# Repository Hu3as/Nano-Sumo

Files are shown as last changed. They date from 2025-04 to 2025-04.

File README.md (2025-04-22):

## <div align="center">Nano sumo fighting robots</div>

 <div align="center">
A robot designed and built as an interactive showcase for a student research group. The set includes two robots in different colors, programmed to detect their opponent using sensors and push them out of the play area. The arena is defined by a special mat or a highly visible tape.
The project is built using three custom-designed PCBs that I developed. These boards integrate a battery management system, an STM32 microcontroller, an LED with a control button, a motor driver, two micro motors, and four optical sensors that detect both the opponent’s position and the boundary lines of the play area.
 </div>

<div align="center">

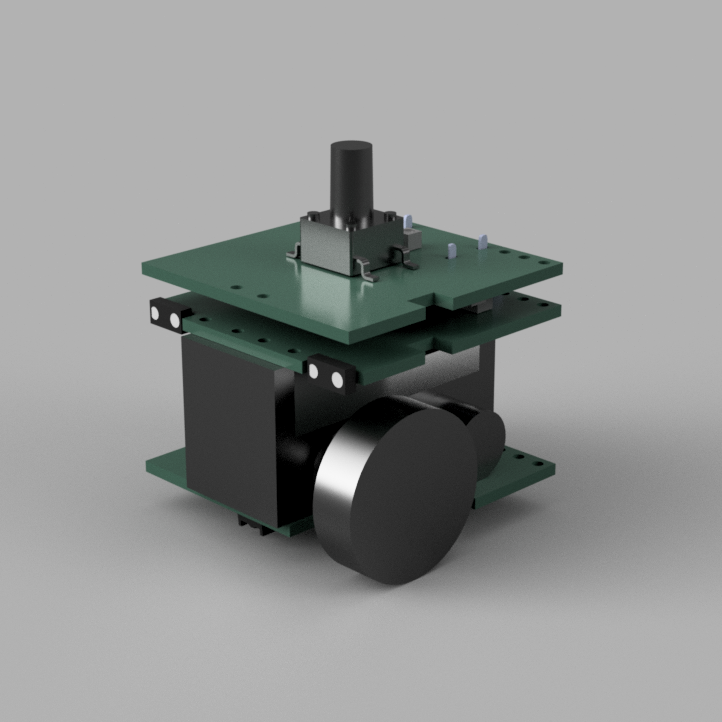
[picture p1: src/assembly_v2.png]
Sumo_REN_1

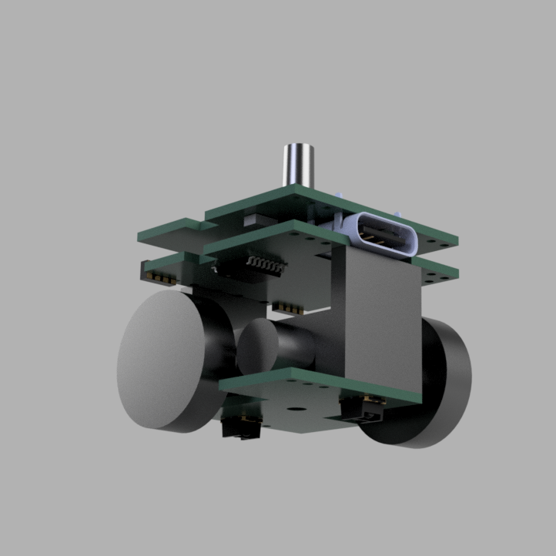
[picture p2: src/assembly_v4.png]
Sumo_REN_2

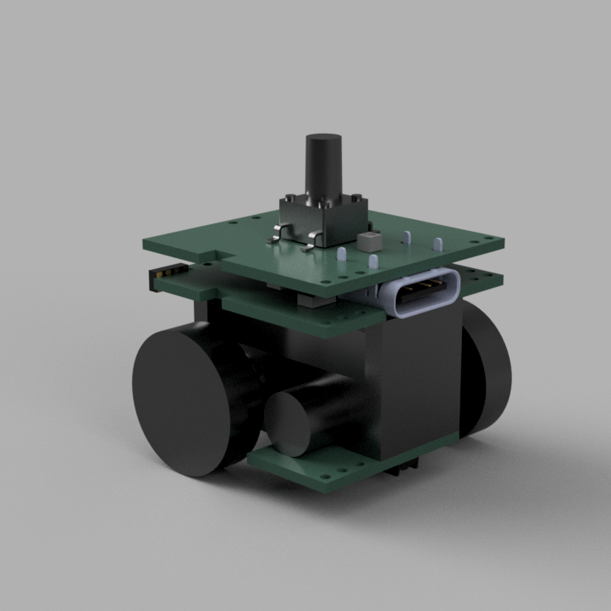
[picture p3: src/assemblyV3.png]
Sumo_REN_3


</div>

### Below are images of the PCB and schematics of the individual modules.

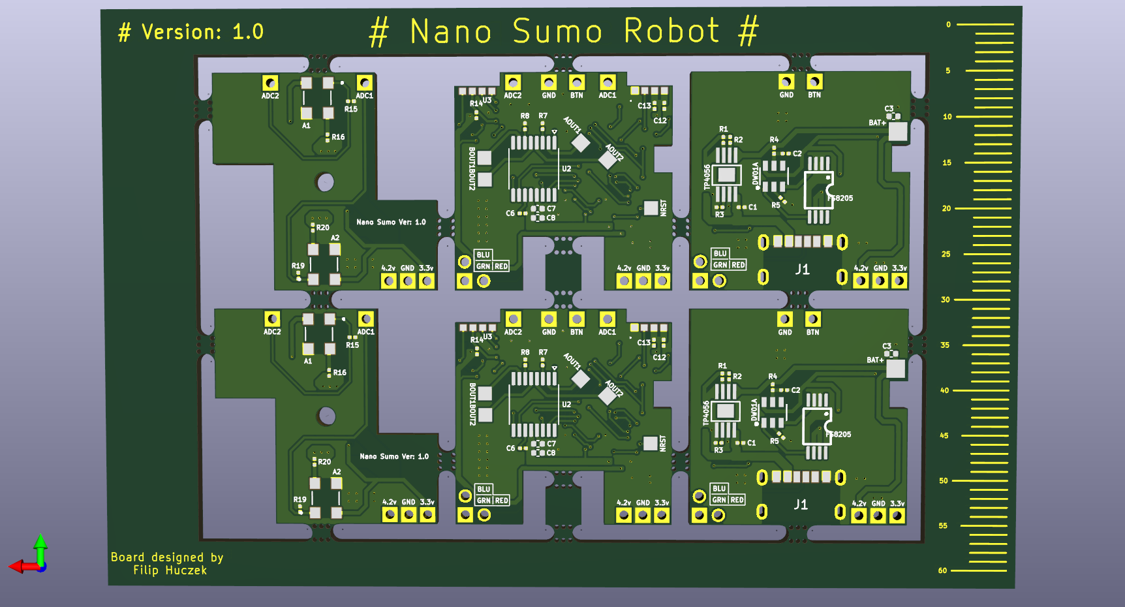
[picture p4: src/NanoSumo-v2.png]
pcb_1

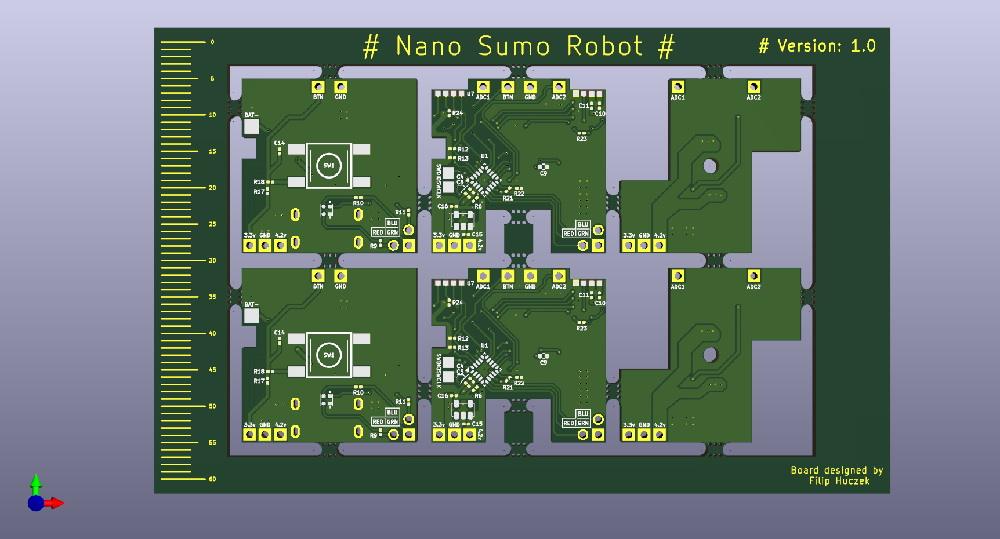
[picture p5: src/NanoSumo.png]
pcb_2


### Schematics

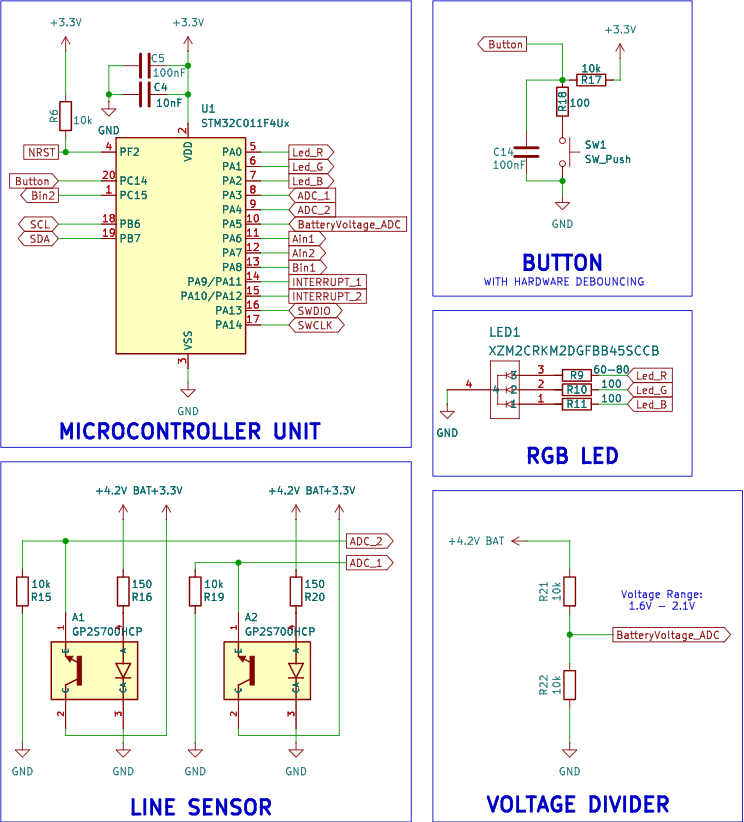
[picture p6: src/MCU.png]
sch_1

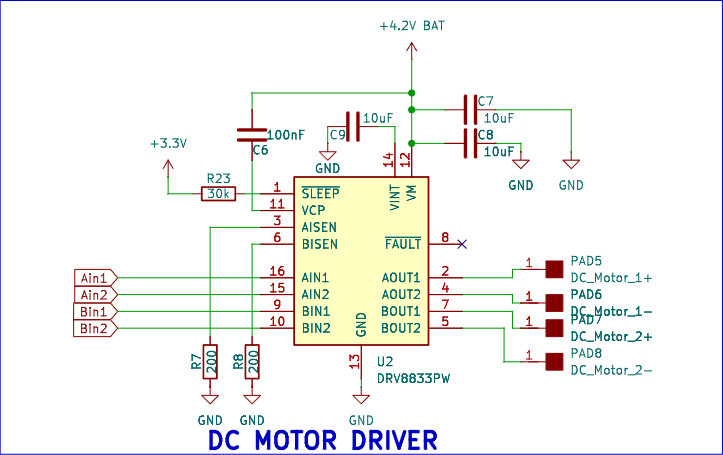
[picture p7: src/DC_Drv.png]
sch_2

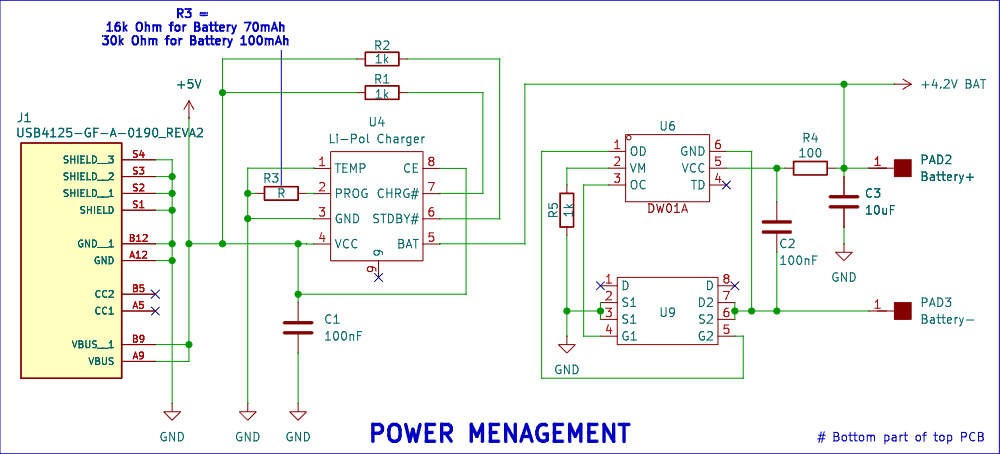
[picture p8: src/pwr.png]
sch_3

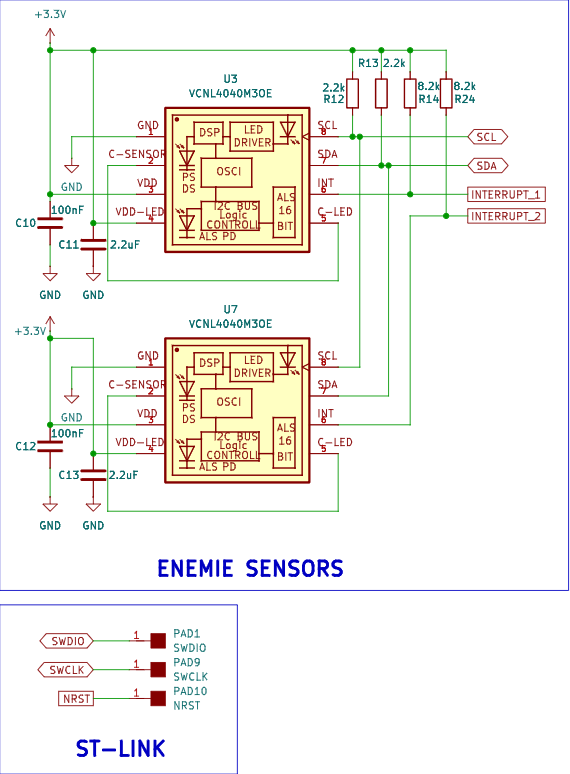
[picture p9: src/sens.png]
sch_4

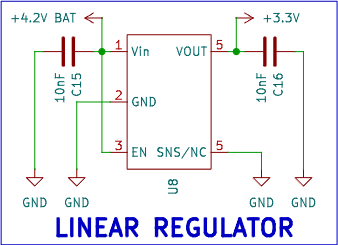
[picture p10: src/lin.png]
sch_5


### All files are available in repository.

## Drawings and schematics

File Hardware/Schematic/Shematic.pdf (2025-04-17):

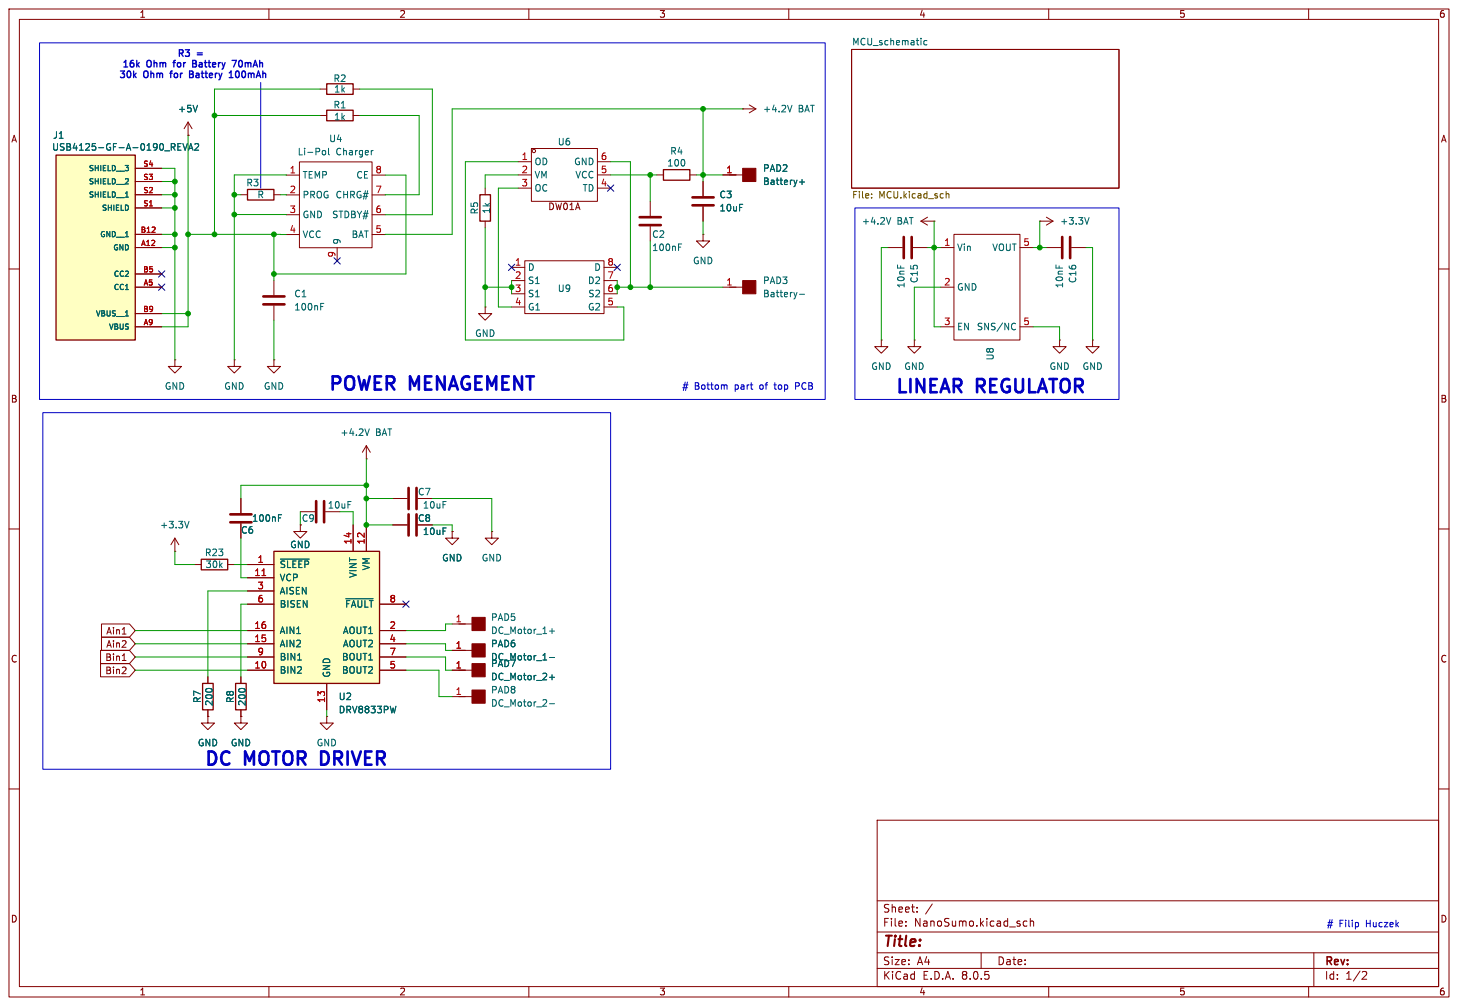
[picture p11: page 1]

Id: 1/2 Title: File: NanoSumo.kicad_sch Sheet: /

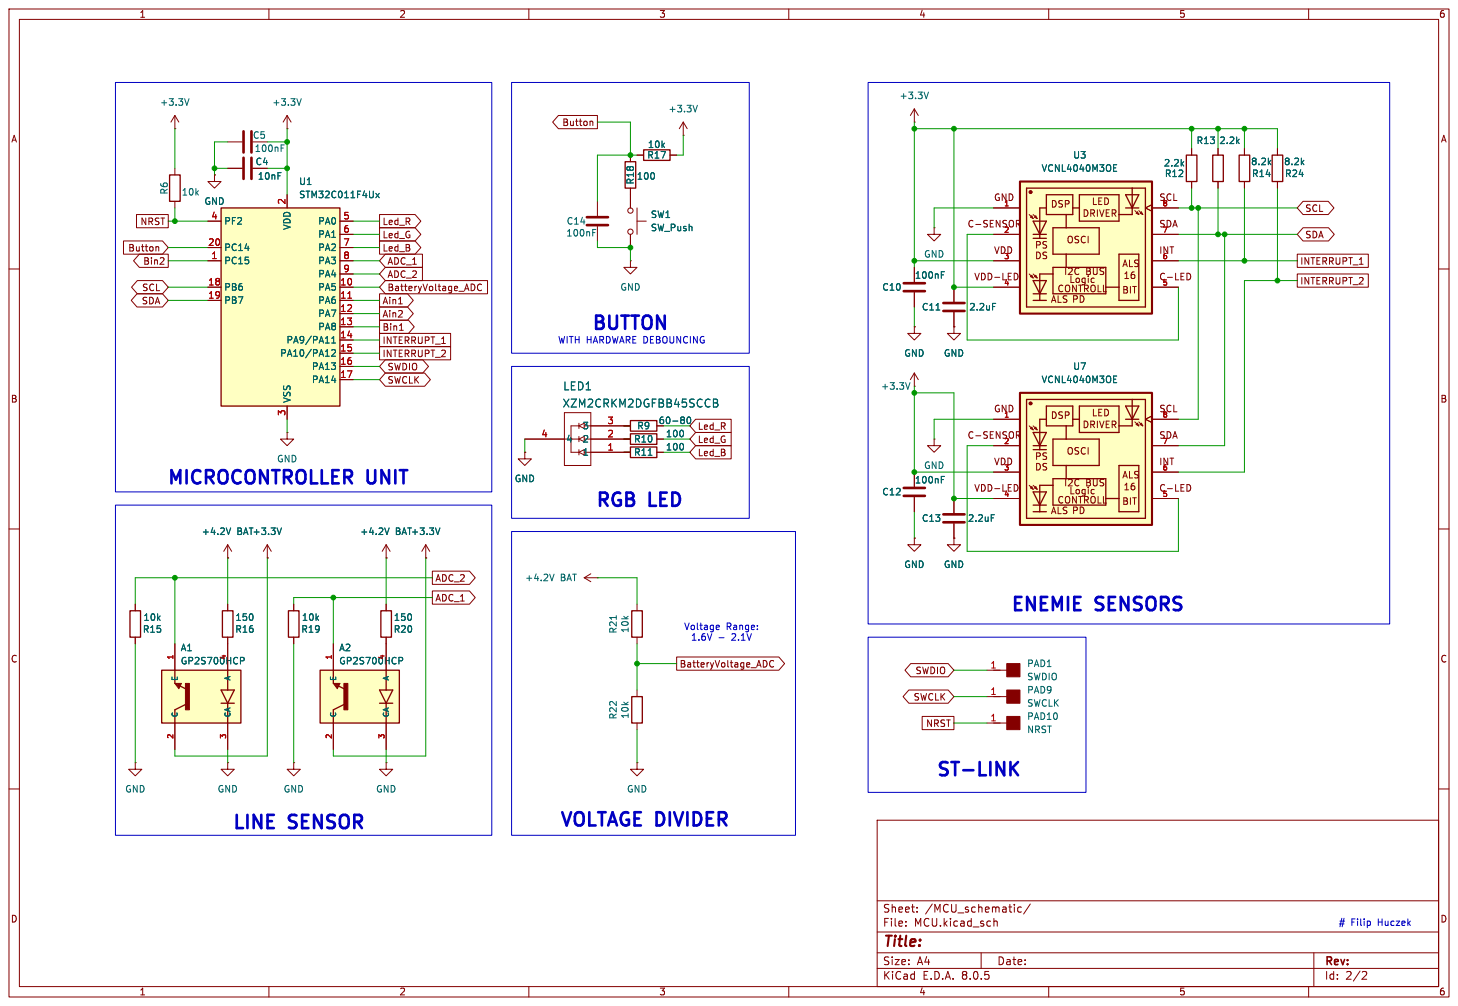
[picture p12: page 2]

# Filip Huczek VOLTAGE DIVIDER

Id: 2/2 Title: File: MCU.kicad_sch Sheet: /MCU_schematic/

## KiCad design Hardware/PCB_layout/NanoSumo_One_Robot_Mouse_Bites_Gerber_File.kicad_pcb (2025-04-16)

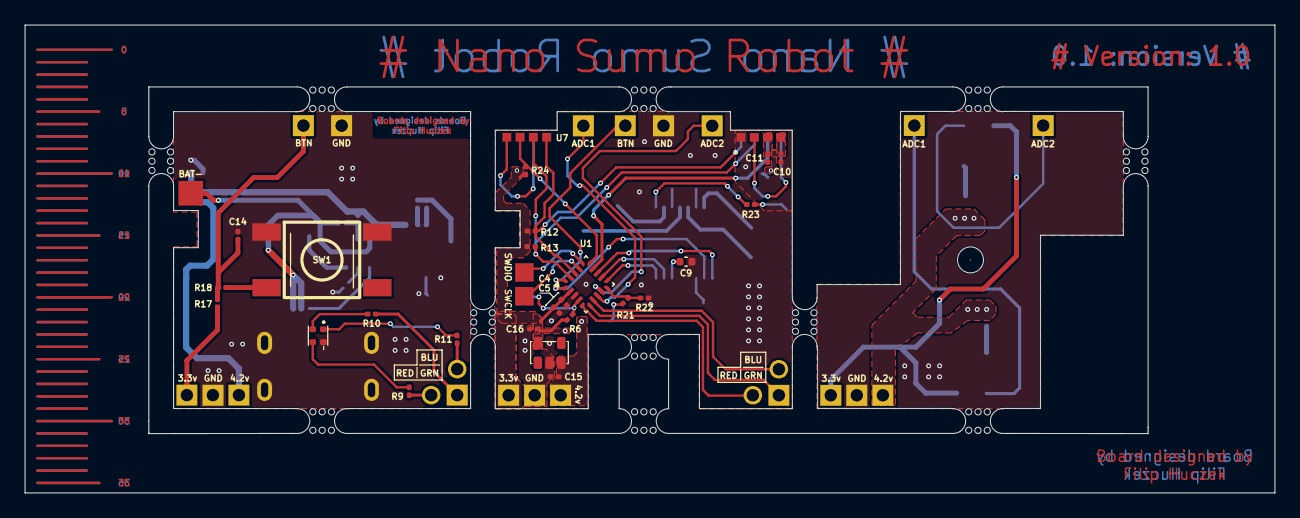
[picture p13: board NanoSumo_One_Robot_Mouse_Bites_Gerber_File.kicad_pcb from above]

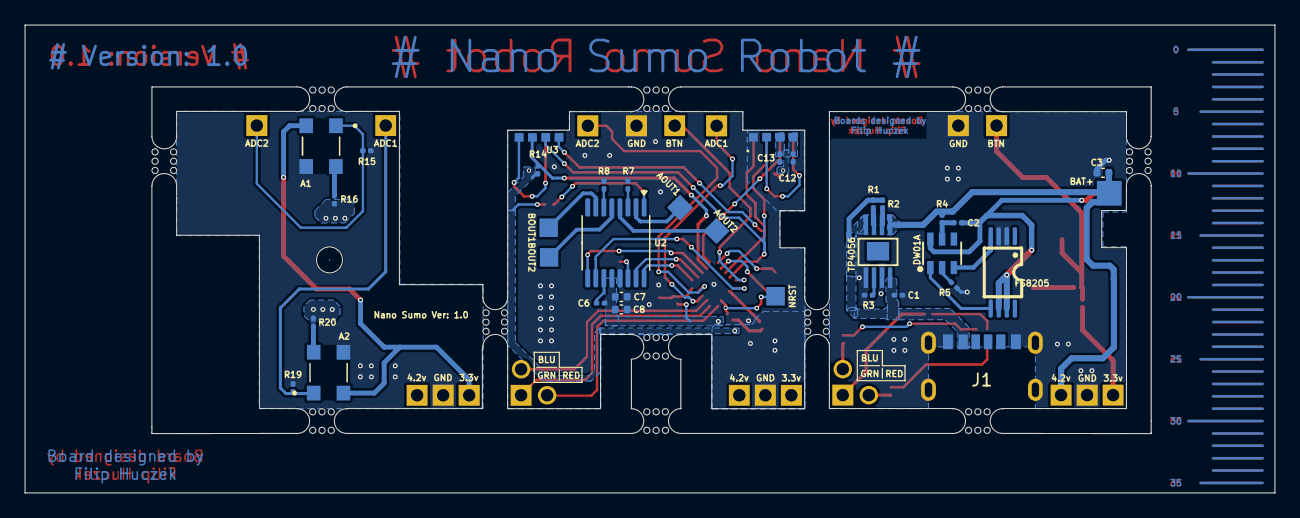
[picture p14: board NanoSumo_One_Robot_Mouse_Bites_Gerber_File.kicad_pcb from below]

Board: 2 copper layers, 101.0 x 37.8 mm, 73 parts (34 on the bottom side), 47 nets.

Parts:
A1, A2: GP2S700HCP; XDCR_GP2S700HCP
AOUT1: DC_Motor_1+; Pad
AOUT2: DC_Motor_1-; Pad
BAT+: Battery+; Pad
BAT-: Battery-; Pad
BOUT1: DC_Motor_2+; Pad
BOUT2: DC_Motor_2-; Pad
C1, C2, C5, C6, C10, C12, C14: 100nF; C_0201_0603Metric
C3, C7, C8, C9: 10uF; C_0402_1005Metric
C4, C15, C16: 10nF; C_0201_0603Metric
C11, C13: 2.2uF; C_0201_0603Metric
J1: USB4125-GF-A-0190_REVA2; GCT_USB4125-GF-A-0190_REVA2
LED1: XZM2CRKM2DGFBB45SCCB; LED_RGB_NanoSumo
NRST: NRST; Pad
R1, R2, R5: 1k; R_0201_0603Metric
R3: R; R_0201_0603Metric
R4, R10, R11, R18: 100; R_0201_0603Metric
R6, R15, R17, R19, R21, R22: 10k; R_0201_0603Metric
R7, R8: 200; R_0201_0603Metric
R9: 60-80; R_0201_0603Metric
R12, R13: 2.2k; R_0201_0603Metric
R14, R24: 8.2k; R_0201_0603Metric
R16, R20: 150; R_0201_0603Metric
R23: 30k; R_0201_0603Metric
SW1: SW_Push; tactile_Switch
SWCLK: SWCLK; Pad
SWDIO: SWDIO; Pad
U1: STM32C011F4Ux; ST_UFQFPN-20_3x3mm_P0.5mm
U2: DRV8833PW; TSSOP-16_4.4x5mm_P0.65mm
U3, U7: VCNL4040M3OE; VISHAY_VCNL4040_4X2X1.1
U4: Li-Pol Charger; TP4056
U6: DW01A
U8: DS9078-20
U9: NM8205A
mouse-bite-2mm-slot, mouse-bite-2mm-slot#2, mouse-bite-2mm-slot#3, mouse-bite-2mm-slot#4, mouse-bite-2mm-slot#5, mouse-bite-2mm-slot#6, mouse-bite-2mm-slot#7, mouse-bite-2mm-slot#8, mouse-bite-2mm-slot#9, mouse-bite-2mm-slot#10, mouse-bite-2mm-slot#11: VAL**; mouse-bite-2mm-slot

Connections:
+3.3V: A1.2 (C), A2.2 (C), C4.2, C5.2, C10.2, C11.2, C12.2, C13.2, C16.2, R6.2, R12.2, R13.2, R14.2, R17.1, R23.1, R24.2, U1.2 (VDD), U3.3, U3.4, U7.3, U7.4, U8.5 (VOUT)
+4.2V BAT: BAT+.1, C3.1, C6.1, C7.1, C8.1, C15.1, R4.2, R16.2, R20.2, R21.2, U2.12 (VM), U4.5 (BAT), U8.1 (Vin), U8.3 (EN)
+5V: C1.1, J1.A9 (VBUS), J1.B9 (VBUS__1), R1.1, R2.1, U4.4 (VCC), U4.8 (CE)
ADC_1: A2.1 (E), R19.2, U1.8 (PA3)
ADC_2: A1.1 (E), R15.2, U1.9 (PA4)
Ain1: U1.11 (PA6), U2.16 (AIN1)
Ain2: U1.12 (PA7), U2.15 (AIN2)
BatteryVoltage_ADC: R21.1, R22.2, U1.10 (PA5)
Bin1: U1.13 (PA8), U2.9 (BIN1)
Bin2: U1.1 (PC15), U2.10 (BIN2)
Button: C14.2, R17.2, R18.1, U1.20 (PC14)
GND: A1.3 (CA), A2.3 (CA), C1.2, C3.2, C4.1, C5.1, C7.2, C8.2, C9.2, C10.1, C11.1, C12.1, C13.1, C14.1, C15.2, C16.1, J1.A12 (GND), J1.B12 (GND__1), J1.S1 (SHIELD), J1.S2 (SHIELD__1), J1.S3 (SHIELD__2), J1.S4 (SHIELD__3), LED1.4, R3.1, R5.1, R7.1, R8.1, R15.1, R19.1, R22.1, SW1.2, U1.3 (VSS), U2.13 (GND), U3.1, U4.1 (TEMP), U4.3 (GND), U7.1, U8.2 (GND), U9.2 (S1), U9.3 (S1)
INTERRUPT_1: R14.1, U1.14 (PA9/PA11), U3.6
INTERRUPT_2: R24.1, U1.15 (PA10/PA12), U7.6
Led_B: R11.1, U1.7 (PA2)
Led_G: R10.1, U1.6 (PA1)
Led_R: R9.2, U1.5 (PA0)
NRST: NRST.1, R6.1, U1.4 (PF2)
unnamed: A1.4 (A), R16.1
unnamed: A2.4 (A), R20.1
unnamed: LED1.1, R11.2
unnamed: LED1.2, R10.2
unnamed: LED1.3, R9.1
unnamed: R18.2, SW1.1
unnamed: R7.2, U2.3 (AISEN)
unnamed: AOUT1.1, U2.2 (AOUT1)
unnamed: AOUT2.1, U2.4 (AOUT2)
unnamed: R8.2, U2.6 (BISEN)
unnamed: BOUT1.1, U2.7 (BOUT1)
unnamed: BOUT2.1, U2.5 (BOUT2)
unnamed: C6.2, U2.11 (VCP)
unnamed: C9.1, U2.14 (VINT)
unnamed: R23.2, U2.1 (~SLEEP)
unnamed: U3.2, U3.5
unnamed: R1.2, U4.7 (CHRG#)
unnamed: R3.2, U4.2 (PROG)
unnamed: R2.2, U4.6 (STDBY#)
unnamed: BAT-.1, C2.2, U6.6 (GND), U9.6 (S2), U9.7 (D2)
unnamed: U6.3 (OC), U9.4 (G1)
unnamed: U6.1 (OD), U9.5 (G2)
unnamed: C2.1, R4.1, U6.5 (VCC)
unnamed: R5.2, U6.2 (VM)
unnamed: U7.2, U7.5
SCL: R12.1, U1.18 (PB6), U3.8, U7.8
SDA: R13.1, U1.19 (PB7), U3.7, U7.7
SWCLK: SWCLK.1, U1.17 (PA14)
SWDIO: SWDIO.1, U1.16 (PA13)

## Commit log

2025-04-16 Hardware files upload
    [NanoSumo.kicad_pcb, NanoSumo.kicad_sch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]
2025-04-22 Rename assembly v2.png to assembly_v2.png
2025-04-22 Rename assembly v4.png to assembly_v4.png
